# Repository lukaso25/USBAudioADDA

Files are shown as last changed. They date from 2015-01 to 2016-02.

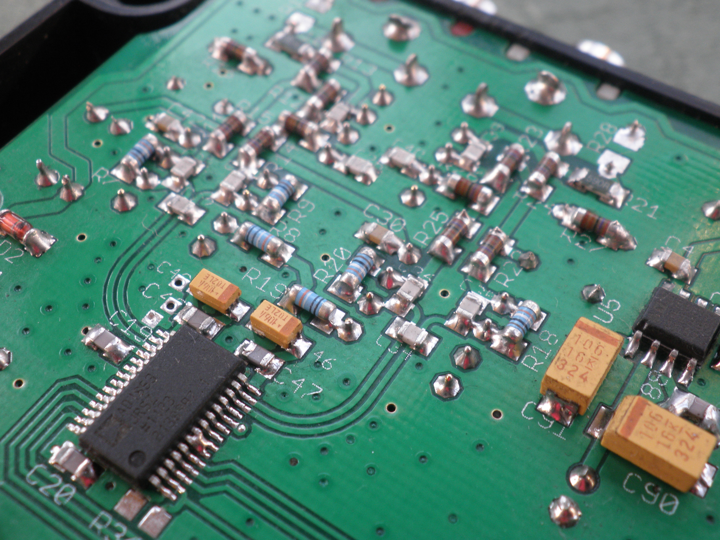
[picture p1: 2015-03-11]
photo prototype/04 dac section.JPG

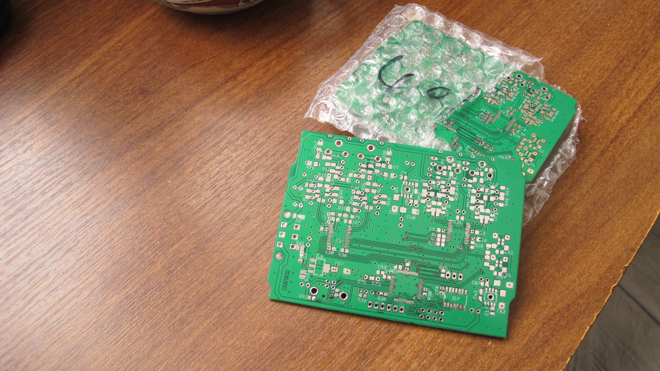
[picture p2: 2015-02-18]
photo prototype/01 pcb.JPG

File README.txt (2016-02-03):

USB Audio ADDA Async
--------------------

This repository contains resources of USB audio interface based on TI microcontroller and Analog devices AD and DA converters. This interface use UAC 1 USB audio specifications, asynchronous clocking scheme. Interface is 24 b/ 96(88.2) kHz  capable in half-duplex mode and 24b / 44.1(48) kHz in full-duplex. 

Only 2 SW modules are relased yet because of unfriendly licencing of USB example code.

Link to pcb photo https://raw.githubusercontent.com/lukaso25/USBAudioADDA/master/photo%20prototype/03%20bottom.JPG

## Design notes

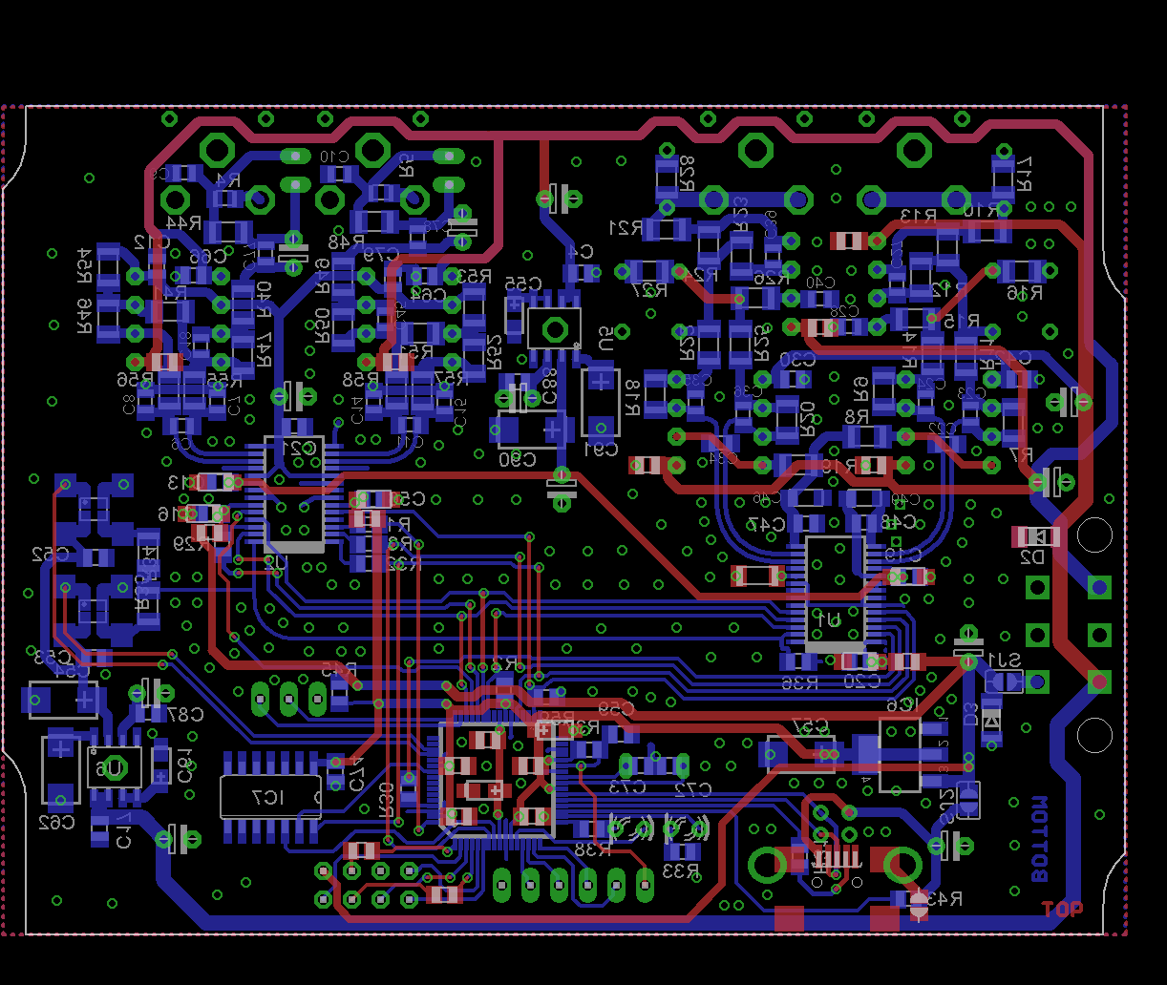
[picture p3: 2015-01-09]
pcbdesign/adcdac.png

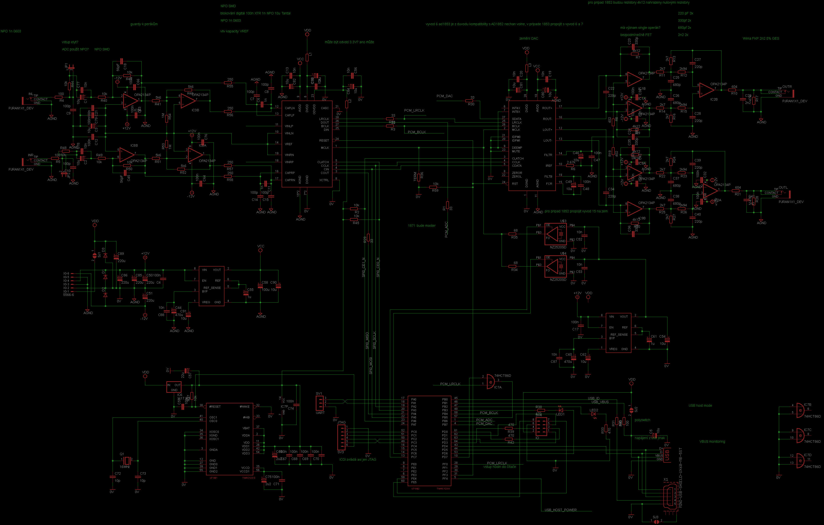
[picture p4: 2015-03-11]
pcbdesign/schema.png

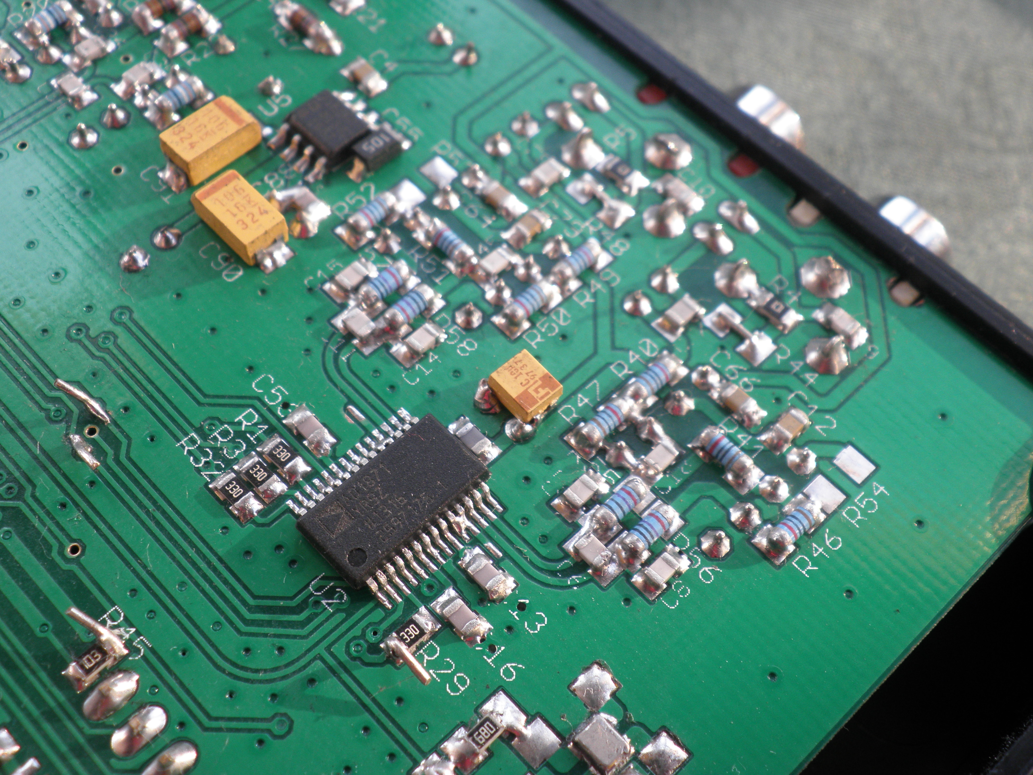
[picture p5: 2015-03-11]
photo prototype/05 ADC section.JPG

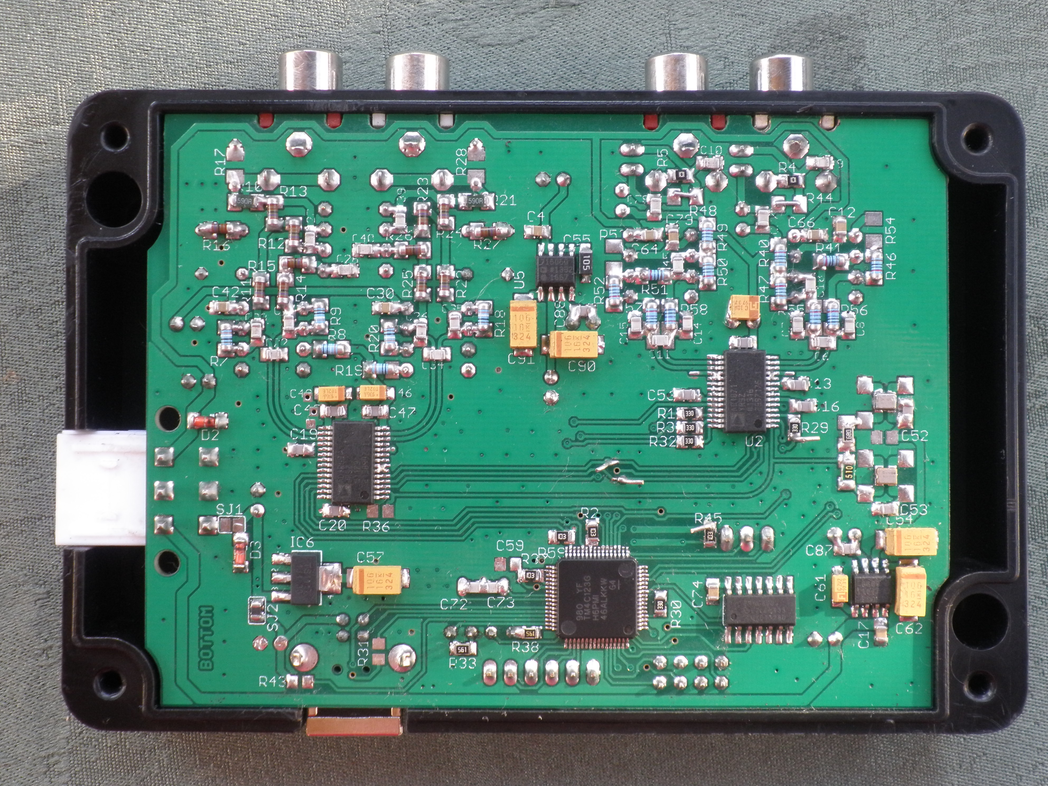
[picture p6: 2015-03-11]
photo prototype/03 bottom.JPG

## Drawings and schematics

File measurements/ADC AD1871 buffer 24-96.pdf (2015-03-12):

## RMS level

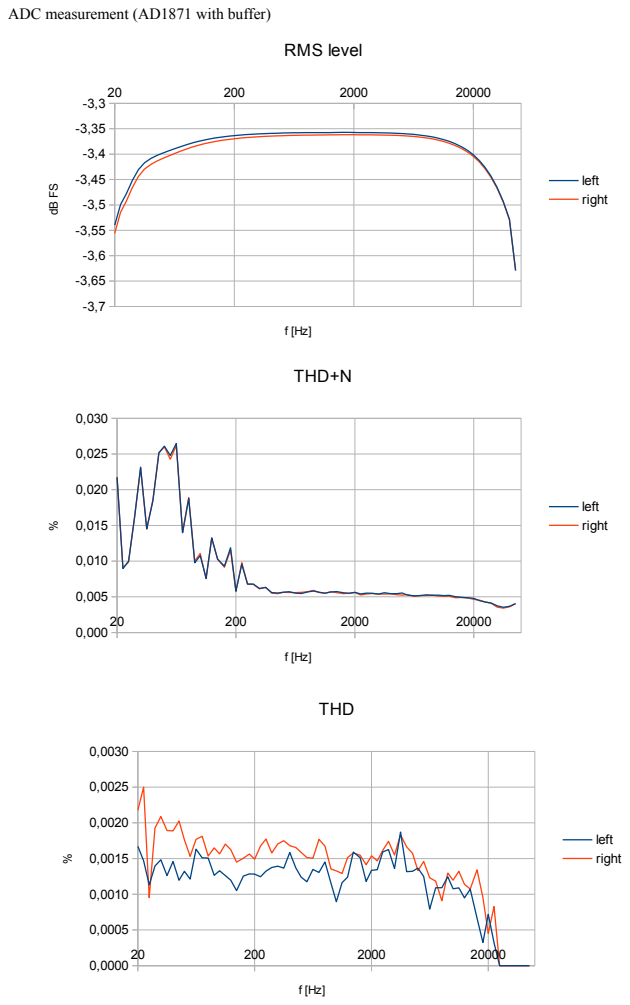
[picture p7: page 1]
left right; THD+N; THD

ADC measurement (AD1871 with buffer)

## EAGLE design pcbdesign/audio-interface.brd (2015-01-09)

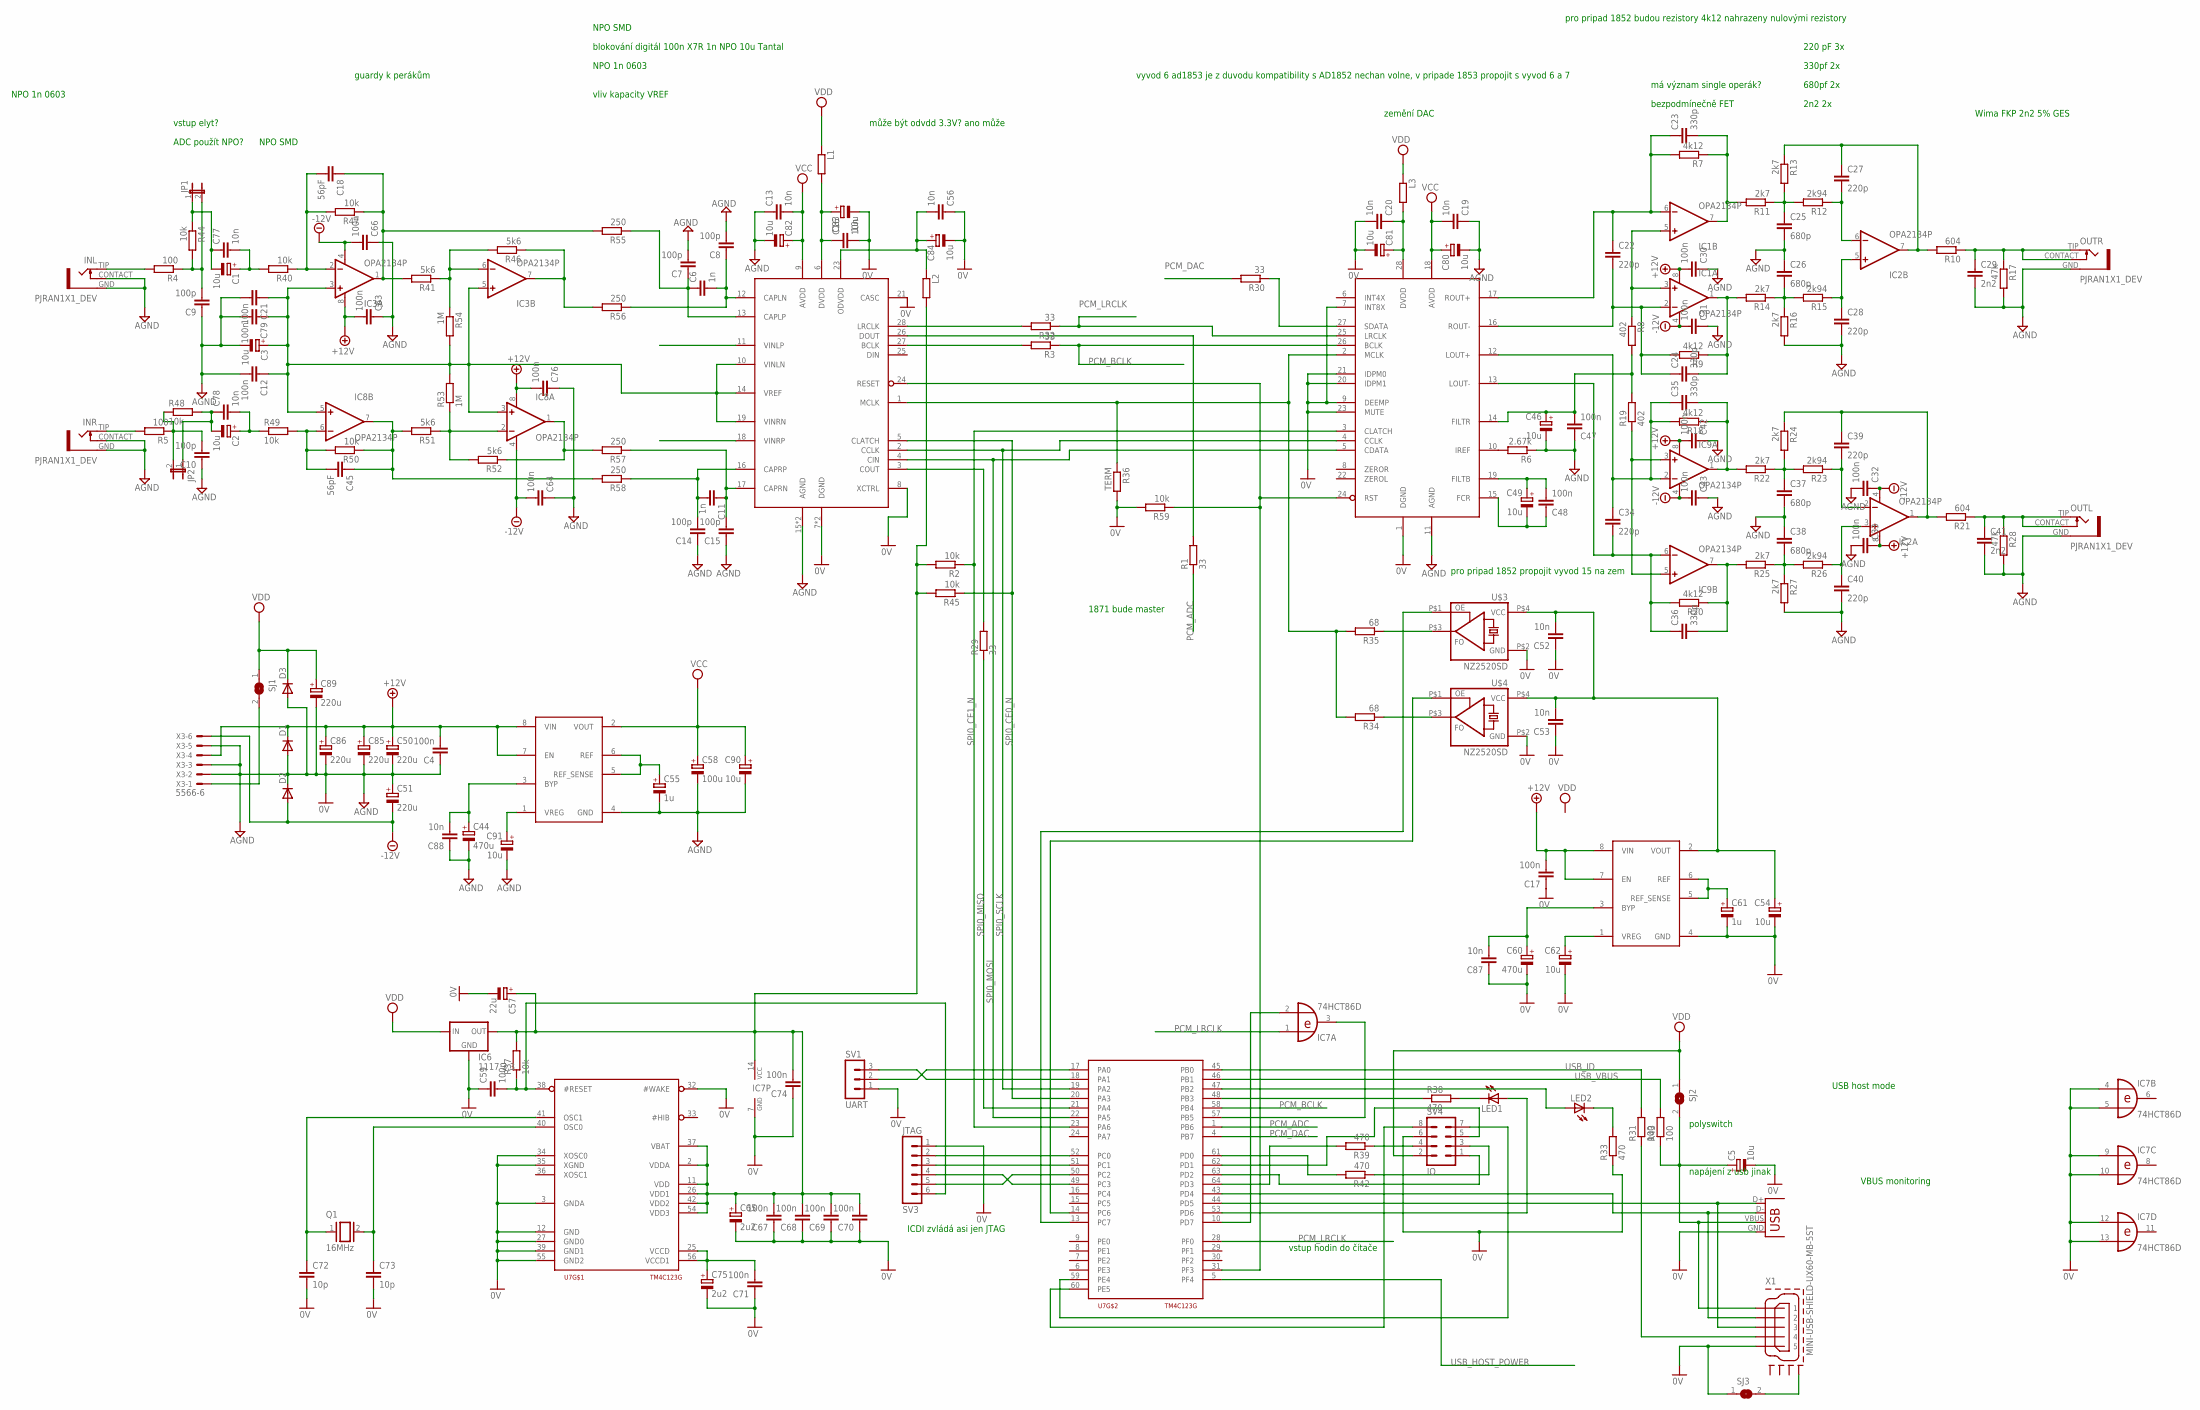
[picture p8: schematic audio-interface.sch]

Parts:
C1, C2: 10u; E2,5-5
C3, C5: 10u; E2,5-7
C4, C12, C17, C21, C30, C31, C32, C33, C42, C43, C47, C48, C59, C63, C64, C66, C67, C68, C69, C70, C71, C74, C76, C79: 100n; C0805
C6, C11: 1n; C0805K
C7, C8, C9, C10, C14, C15: 100p; C0805K
C13, C16, C19, C20, C52, C53, C56, C87, C88: 10n; C0805
C18, C45: 56pF; C0805K
C22, C27, C28, C34, C39, C40: 220p; C0805K
C23, C24, C35, C36: 330p; C0805K
C25, C26, C37, C38: 680p; C050-050X075
C29, C41: 2n2; C050-050X075
C44, C60: 470u; E2,5-7
C46, C49, C80, C81, C82, C83, C84: 10u; SMC_A
C50, C51, C85, C86, C89: 220u; E2,5-7
C54, C62, C90, C91: 10u; CT6032
C55, C61: 1u; CT3216
C57: 22u; CT6032
C58: 100u; E2,5-7
C65, C75: 2u2; CT3216
C72, C73: 10p; C0805
C77, C78: 10n; C0805K
D1, D2, D3: DIODE-MINIMELF; MINIMELF
IC1, IC3, IC8, IC9: OPA2134P; DIL08; MPN OPA2134PA
IC2: OPA2134P; DIL08
IC6: 1117 3.3; SOT223
IC7: 74HCT86D; SO14
INL: PJRAN1X1_DEV; PJRAN1X1
INR: PJRAN1X1_DEV; PJRAN1X1
JP1, JP2: JP1E; JP1
L1, L2, L3: R-EU_R0805; R0805
LED1, LED2: LED3MM
OUTL: PJRAN1X1_DEV; PJRAN1X1
OUTR: PJRAN1X1_DEV; PJRAN1X1
Q1: 16MHz; QS
R1, R3, R29, R30, R32: 33; R0805
R2, R37, R45, R59: 10k; R0805
R4, R5: 100; M0805
R6: 2.67k; M1406
R7, R9, R18, R20: 4k12; M1206
R8, R19: 402; M1206
R10, R21: 604; M1206
R11, R13, R14, R16, R22, R24, R25, R27: 2k7; M1206
R12, R15, R23, R26: 2k94; M1206
R17, R28: 47k; M1206
R31, R43: 100; R0805
R33, R38, R39, R42: 470; R0805
R34, R35: 68; M1206
R36: TERM; R0805
R40, R44, R47, R48, R49, R50: 10k; M1206
R41, R46, R51, R52: 5k6; M1206
R53, R54: 1M; M1206
R55, R56, R57, R58: 250; M1206
SJ1, SJ2, SJ3: SJ
SV1: UART; MA03-1
SV3: JTAG; MA06-1
SV4: IO; MA04-2
U1: AD1853; SSOP-28
U2: AD1871; SSOP-28
U5, U6: ADM7150; SO8-COOL
U7: TM4C123G; LQFP64
U$3, U$4: NZ2520SD; OSC2X2.5
X1: MINI-USB-SHIELD-UX60-MB-5ST; UX60-MB-5ST
X3: 5566-6
X7: USB-B-H

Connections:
+12V: C4.2, C17.2, C30.2, C33.1, C42.2, C50.+, C63.2, C76.2, C85.+, C86.+, D1.C, IC1.8 (V+), IC2.8 (V+), IC3.8 (V+), IC8.8 (V+), IC9.8 (V+), U5.7 (EN), U5.8 (VIN), U6.7 (EN), U6.8 (VIN), X3.4
-12V: C31.2, C32.1, C43.2, C51.-, C64.2, C66.2, D2.A, IC1.4 (V-), IC2.4 (V-), IC3.4 (V-), IC8.4 (V-), IC9.4 (V-), X3.6
AGND: C3.-, C4.1, C5.-, C7.2, C8.2, C9.1, C10.1, C12.2, C13.1, C14.1, C15.1, C16.2, C17.1, C19.1, C20.2, C21.2, C25.2, C26.1, C28.2, C29.2, C30.1, C31.1, C32.2, C33.2, C37.2, C38.1, C40.2, C41.2, C42.1, C43.1, C44.-, C46.-, C47.1, C50.-, C51.+, C52.1, C53.1, C54.-, C55.-, C56.1, C57.-, C58.-, C59.1, C60.-, C61.-, C62.-, C63.1, C64.1, C65.-, C66.1, C67.1, C68.1, C69.1, C70.1, C71.1, C72.2, C73.2, C74.1, C75.-, C76.1, C79.2, C80.-, C81.-, C82.-, C83.-, C84.-, C85.-, C86.-, C87.1, C88.1, C89.-, C90.-, C91.-, D1.A, D2.C, D3.A, IC6.1 (GND), IC7.4 (I0), IC7.5 (I1), IC7.7 (GND), IC7.9 (I0), IC7.10 (I1), IC7.12 (I0), IC7.13 (I1), INL.CONTACT (SWITCH), INL.GND, INR.CONTACT (SWITCH), INR.GND, OUTL.GND, OUTR.GND, R6.1, R16.2, R17.2, R27.2, R28.2, R33.1, R36.2, R59.2, SJ3.1, SV1.1, SV3.1, SV4.6, U1.1 (DGND), U1.7 (INT8X), U1.9 (DEEMP), U1.11 (AGND), U1.20 (IDPM1), U1.21 (IDPM0), U1.23 (MUTE), U2.7 (DGND), U2.8 (XCTRL), U2.15 (AGND), U2.20 (AGND), U2.21 (CASC), U2.22 (DGND), U5.4 (GND), U6.4 (GND), U7.3 (GNDA), U7.12 (GND), U7.27 (GND0), U7.32 (#WAKE), U7.34 (XOSC0), U7.35 (XGND), U7.39 (GND1), U7.55 (GND2), U$3.P$2 (GND), U$4.P$2 (GND), X1.5, X3.2, X3.3, X3.5, X7.GND
unnamed: R59.1, U1.24 (RST), U2.24 (RESET), U7.31 (PF3)
unnamed: R35.1, U$3.P$3 (FO)
unnamed: R32.2, U2.28 (LRCLK)
unnamed: IC7.3 (O), U7.57 (PB5)
unnamed: R1.2, U2.26 (DOUT)
unnamed: C55.+, U5.5 (REF_SENSE), U5.6 (REF)
unnamed: C91.+, U5.1 (VREG)
unnamed: C44.+, C88.2, U5.3 (BYP)
unnamed: R34.2, R35.2, R36.1, U1.2 (MCLK), U2.1 (MCLK)
unnamed: C6.2, C8.1, R56.1, U2.12 (CAPLN)
unnamed: R29.2, U2.3 (COUT)
unnamed: C60.+, C87.2, U6.3 (BYP)
unnamed: C62.+, U6.1 (VREG)
unnamed: C61.+, U6.5 (REF_SENSE), U6.6 (REF)
unnamed: C1.+, C77.2, R40.2
unnamed: IC3.7 (OUT), R46.1, R56.2
unnamed: C71.2, C75.+, U7.25 (VCCD), U7.56 (VCCD1)
unnamed: C22.2, C24.1, IC1.2 (-IN), R9.2, U1.16 (ROUT-)
unnamed: C6.1, C7.1, R55.1, U2.13 (CAPLP)
unnamed: C45.1, IC8.7 (OUT), R50.1, R51.2, R58.2
unnamed: C11.1, C15.2, R57.1, U2.17 (CAPRN)
unnamed: C22.1, C23.1, IC1.6 (-IN), R7.2, U1.17 (ROUT+)
unnamed: SV1.3, U7.18 (PA1)
unnamed: IC8.1 (OUT), R52.1, R57.2
unnamed: C24.2, IC1.1 (OUT), R9.1, R14.2
unnamed: C11.2, C14.2, R58.1, U2.16 (CAPRP)
unnamed: IC8.2 (-IN), R51.1, R52.2, R53.1
unnamed: IC3.6 (-IN), R41.1, R46.2, R54.1
unnamed: C3.+, C12.1, C21.1, C79.1, IC3.3 (+IN), IC3.5 (+IN), IC8.3 (+IN), IC8.5 (+IN), R53.2, R54.2, U2.10 (VINLN), U2.14 (VREF), U2.19 (VINRN)
unnamed: C23.2, IC1.7 (OUT), R7.1, R11.2
unnamed: C46.+, C47.2, R8.2, R19.2, U1.14 (FILTR)
unnamed: C26.2, R14.1, R15.2, R16.1
unnamed: R6.2, U1.10 (IREF)
unnamed: C25.1, R11.1, R12.2, R13.2
unnamed: C27.2, IC2.6 (-IN), R12.1
unnamed: C28.1, IC2.5 (+IN), R15.1
unnamed: C27.1, IC2.7 (OUT), R10.2, R13.1
unnamed: C48.2, C49.+, U1.19 (FILTB)
unnamed: C29.1, OUTR.CONTACT (SWITCH), OUTR.TIP (HOT), R10.1, R17.1
unnamed: C48.1, C49.-, U1.15 (FCR)
unnamed: SV3.5, U7.50 (PC2)
unnamed: C34.2, C36.1, IC9.6 (-IN), R20.2, U1.13 (LOUT-)
unnamed: C36.2, IC9.7 (OUT), R20.1, R25.2
unnamed: IC9.3 (+IN), IC9.5 (+IN), R19.1
unnamed: C35.2, IC9.1 (OUT), R18.1, R22.2
unnamed: C38.2, R25.1, R26.2, R27.1
unnamed: C37.1, R22.1, R23.2, R24.2
unnamed: C39.2, IC2.2 (-IN), R23.1
unnamed: C40.1, IC2.3 (+IN), R26.1
unnamed: C39.1, IC2.1 (OUT), R21.2, R24.1
unnamed: R3.2, U2.27 (BCLK)
unnamed: IC1.3 (+IN), IC1.5 (+IN), R8.1
unnamed: C18.1, IC3.1 (OUT), R41.2, R47.1, R55.2
unnamed: INR.TIP (HOT), R5.2
unnamed: C10.2, JP2.2, R5.1, R48.1
unnamed: R34.1, U$4.P$3 (FO)
unnamed: C34.1, C35.1, IC9.2 (-IN), R18.2, U1.12 (LOUT+)
unnamed: C2.+, C78.2, R49.1
unnamed: C72.1, Q1.1, U7.41 (OSC1)
unnamed: C52.2, C53.2, C54.+, U6.2 (VOUT), U$3.P$4 (VCC), U$4.P$4 (VCC)
unnamed: C45.2, IC8.6 (-IN), R49.2, R50.2
unnamed: C73.1, Q1.2, U7.40 (OSC0)
unnamed: SV4.1, U7.63 (PD2)
unnamed: SV1.2, U7.17 (PA0)
unnamed: R39.2, U7.64 (PD3)
unnamed: SV3.4, U7.49 (PC3)
unnamed: LED1.A, U7.53 (PD6)
unnamed: C18.2, IC3.2 (-IN), R40.1, R47.2
unnamed: C9.2, JP1.2, R4.1, R44.2
unnamed: INL.TIP (HOT), R4.2
unnamed: U7.44 (PD5), X1.3, X7.D+
unnamed: U7.43 (PD4), X1.2, X7.D-
unnamed: C59.2, R37.1, SV3.6, U7.38 (#RESET)
unnamed: SV3.2, U7.52 (PC0)
unnamed: SV3.3, U7.51 (PC1)
unnamed: IC7.2 (I1), U7.10 (PD7)
unnamed: LED2.K (C), R33.2
unnamed: LED1.K (C), R38.2
unnamed: U7.14 (PC6), U$4.P$1 (OE)
unnamed: U7.13 (PC7), U$3.P$1 (OE)
unnamed: R42.2, U7.61 (PD0)
unnamed: C16.1, C83.+, L1.2, U2.6 (DVDD)
unnamed: C56.2, C84.+, L2.1, U2.23 (ODVDD)
unnamed: R38.1, U7.48 (PB3)
unnamed: C57.+, C65.+, C67.2, C68.2, C69.2, C70.2, C74.2, IC6.2 (OUT), IC7.14 (VCC), L2.2, R2.2, R37.2, R45.2, U7.2 (VDDA), U7.11 (VDD), U7.26 (VDD1), U7.37 (VBAT), U7.42 (VDD2), U7.54 (VDD3)
unnamed: R30.1, U1.27 (SDATA)
unnamed: R39.1, SV4.4
unnamed: SV4.8, U7.60 (PE5)
unnamed: SV4.5, U7.62 (PD1)
unnamed: R42.1, SV4.3
unnamed: SV4.7, U7.59 (PE4)
unnamed: C1.-, C77.1, JP1.1, R44.1
unnamed: C2.-, C78.1, JP2.1, R48.2
unnamed: LED2.A, U7.47 (PB2)
unnamed: C20.1, C81.+, L3.2, U1.28 (DVDD)
unnamed: SJ1.2, X3.1
unnamed: C5.+, R43.1, SJ2.2, X1.1, X7.VBUS
unnamed: R31.1, X1.4
unnamed: SJ3.2, X1.M4 (GND4)
OUTL: C41.1, OUTL.CONTACT (SWITCH), OUTL.TIP (HOT), R21.1, R28.1
PCM_ADC: R1.1, U7.1 (PB6)
PCM_BCLK: R3.1, U1.26 (BCLK), U7.58 (PB4)
PCM_DAC: R30.2, U7.4 (PB7)
PCM_LRCLK: IC7.1 (I0), R32.1, U1.25 (LRCLK), U7.28 (PF0)
SPI0_CE0_N: R45.1, U2.5 (CLATCH), U7.20 (PA3)
SPI0_CE1_N: R2.1, U1.3 (CLATCH), U7.23 (PA6)
SPI0_MISO: R29.1, U7.21 (PA4)
SPI0_MOSI: U1.5 (CDATA), U2.4 (CIN), U7.22 (PA5)
SPI0_SCLK: U1.4 (CCLK), U2.2 (CCLK), U7.19 (PA2)
USB_HOST_POWER: U7.5 (PF4)
USB_ID: R31.2, U7.45 (PB0)
USB_VBUS: R43.2, U7.46 (PB1)
VCC: C13.2, C19.2, C58.+, C80.+, C82.+, C90.+, U1.18 (AVDD), U2.9 (AVDD), U5.2 (VOUT)
VDD: C89.+, D3.C, IC6.3 (IN), L1.1, L3.1, SJ1.1, SJ2.1, SV4.2

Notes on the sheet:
1871 bude master
bezpodmínečně FET
může být odvdd 3.3V? ano může
ICDI zvládá asi jen JTAG
USB host mode
vstup elyt?
ADC použít NPO?
NPO SMD
blokování digitál 100n X7R 1n NPO 10u Tantal
NPO 1n 0603
vliv kapacity VREF
zemění DAC
220 pF 3x
330pf 2x
680pf 2x
2n2 2x
má význam single operák?
Wima FKP 2n2 5% GES
vstup hodin do čítače
napájení z usb jinak
VBUS monitoring
guardy k perákům
polyswitch
vyvod 6 ad1853 je z duvodu kompatibility s AD1852 nechan volne, v pripade 1853 propojit s vyvod 6 a 7
pro pripad 1852 propojit vyvod 15 na zem
pro pripad 1852 budou rezistory 4k12 nahrazeny nulovými rezistory

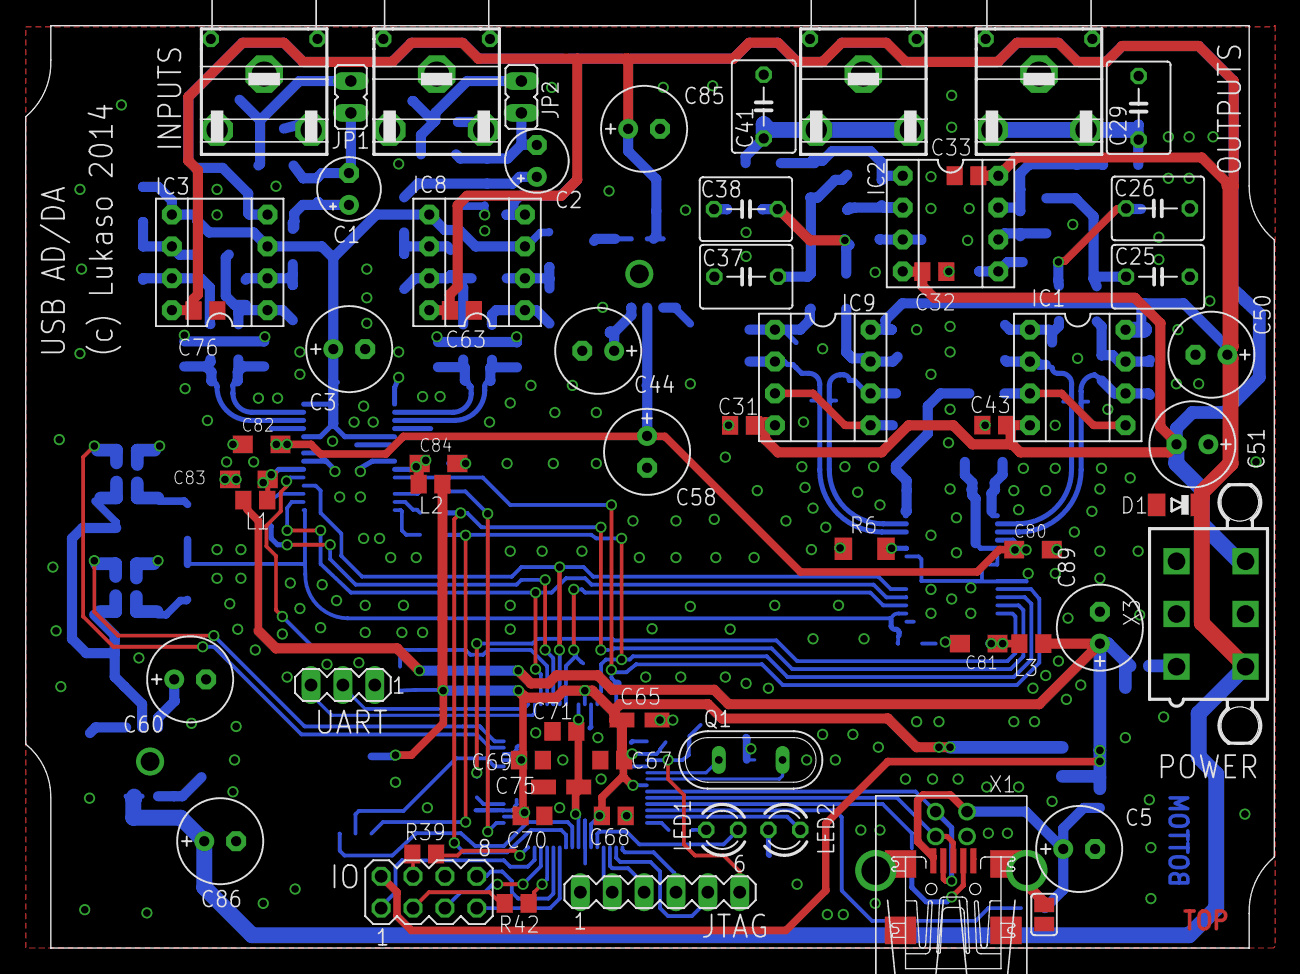
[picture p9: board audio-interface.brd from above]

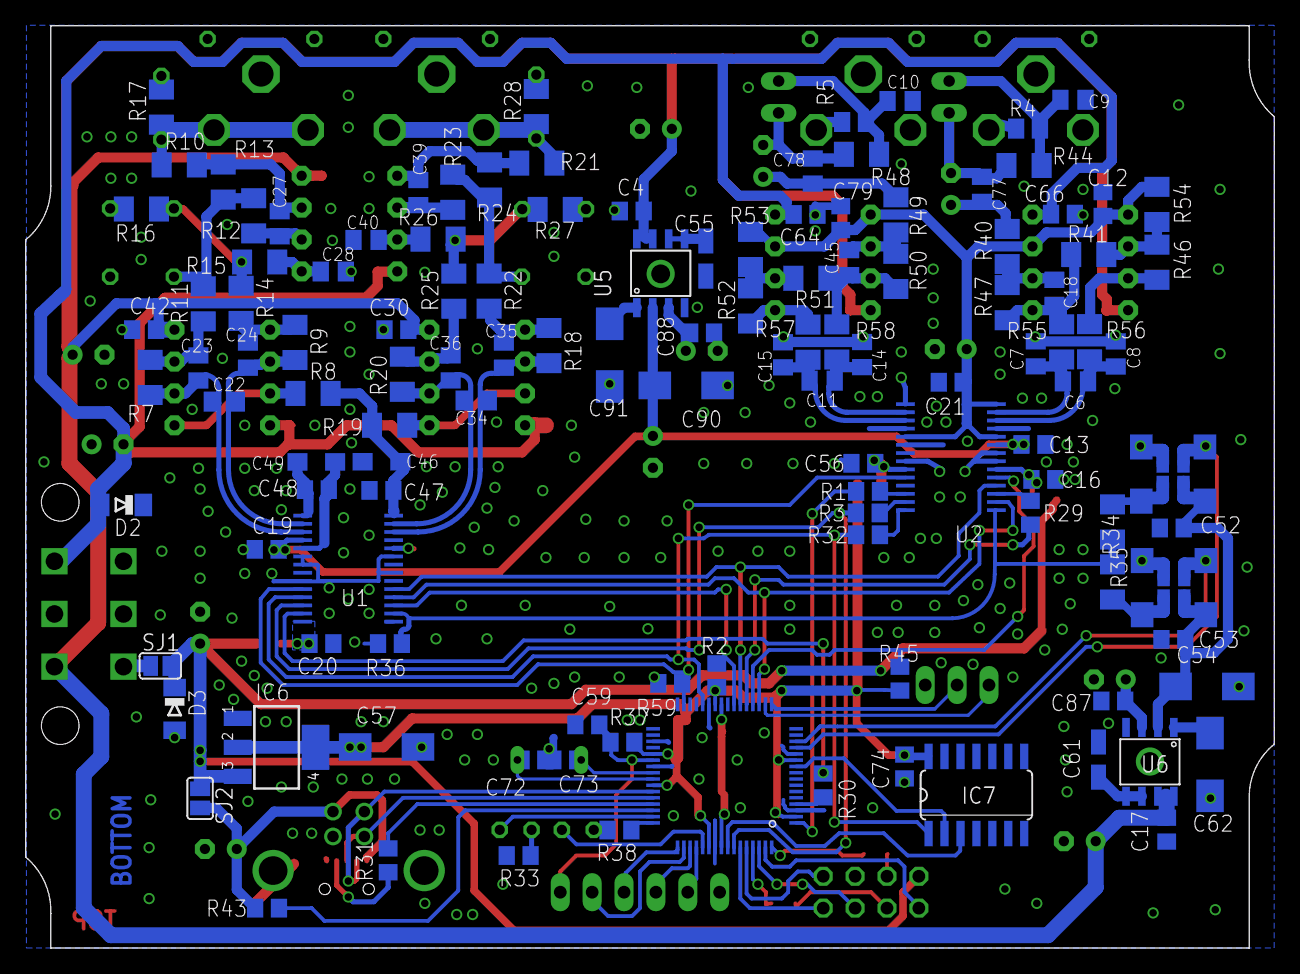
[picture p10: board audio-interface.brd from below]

Board: 2 copper layers, 99.5 x 73.5 mm, 188 parts (124 on the bottom side), 116 nets.

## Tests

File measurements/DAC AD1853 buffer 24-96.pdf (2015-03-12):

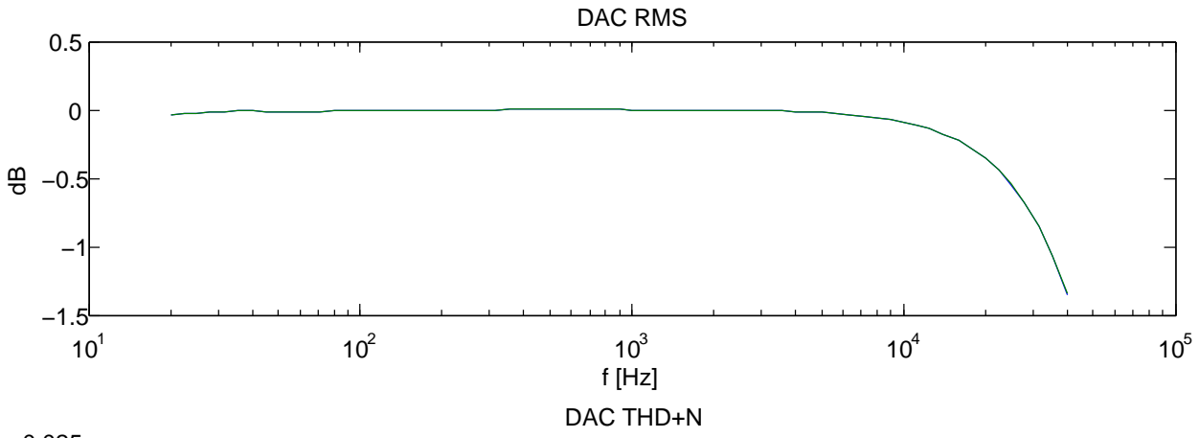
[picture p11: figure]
DAC RMS; DAC THD+N
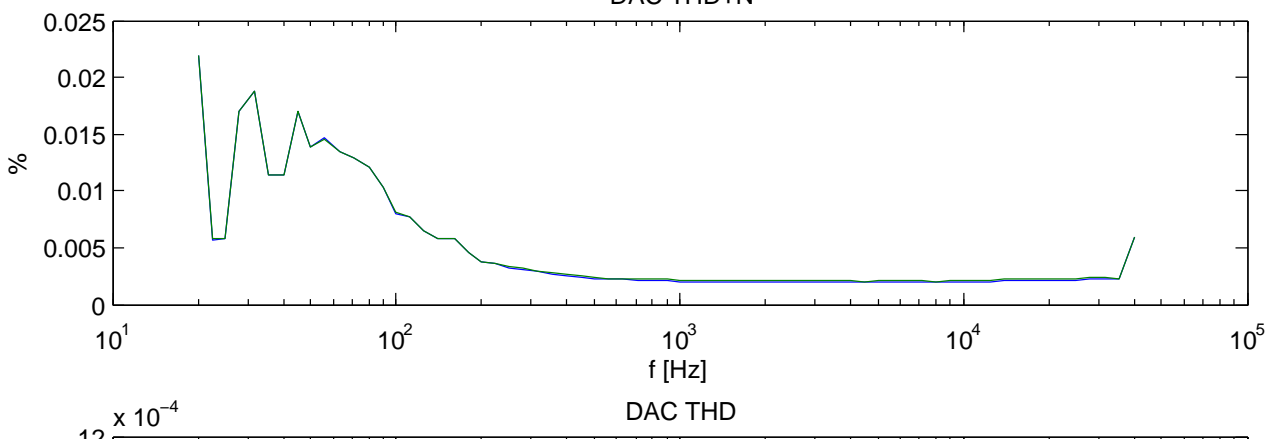
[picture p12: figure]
DAC THD
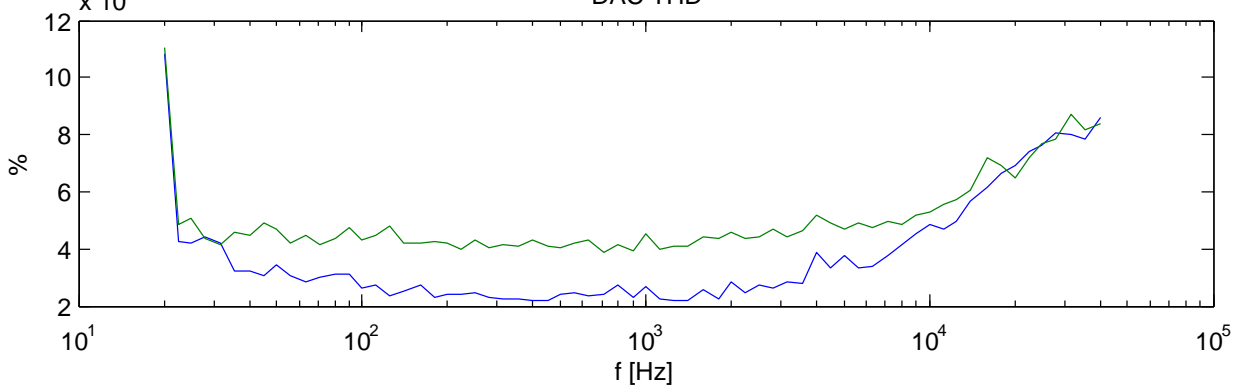
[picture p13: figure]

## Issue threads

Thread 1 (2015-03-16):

glitches during recording and monitoring

lukaso25, 2015-03-16:
There are some glitcher during recording with monitoring (full-duplex, observed in Samplitude 8 and Audacity DAW).

Testing suggestions:
- Is problem present on different UAC 1 device?
- Is problem related to synchronization of output (asynchronous audio).
- Is problem related only to MS Windows AUC1 audio implementation?

HW with current SW release should be debugged with loggic analyzer during recording initialization and recording glitches (output buffer state).

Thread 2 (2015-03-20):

Power management

lukaso25, 2015-03-20:
There are many problems with power management, which should be solved.

- what is specified by usb for suspend mode?
- what is actual power consumption during suspend mode?
- external power supply is used for analog, and sample rate clock  - how to handle absence of this supply, how to handle suspend signaling?

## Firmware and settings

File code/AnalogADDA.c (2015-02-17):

#include "AnalogADDA.h"

#include "inc/hw_memmap.h"
#include "inc/hw_types.h"
#include "inc/hw_ssi.h"
#include "inc/hw_gpio.h"
#include "inc/hw_ints.h"
#include "driverlib/ssi.h"
#include "driverlib/interrupt.h"
#include "driverlib/pin_map.h"
#include "driverlib/gpio.h"
#include "driverlib/rom.h"
#include "driverlib/sysctl.h"

#include "main.h"

uint32_t actual_samplerate;
static uint16_t AD1871_0_gain_hp_amc, AD1871_1_mute_fmt, AD1871_2_mux_mck;
static uint16_t AD185x_conf;
const uint16_t volumeLookUp[128];

uint16_t AnalogADDASPItransfer(uint8_t chip, uint16_t data);

uint16_t AnalogADDASPItransfer(uint8_t chip, uint16_t data)
{
	volatile uint16_t delay;
	GPIOPinWrite(GPIO_PORTA_BASE, chip, 0);
	//delay = 0xFF;
	//while (delay){delay--;};
	//temp = (1<<5)|1; // 24 bit, LJ, without mute
	SSIDataPut(SSI0_BASE,data);
	while(SSIBusy(SSI0_BASE)){};
	//delay = 0x0F;
	//while (delay){delay--;};
	GPIOPinWrite(GPIO_PORTA_BASE, chip, chip);
	delay = 0xFF;
	while (delay){delay--;};
	return 0;
}



uint16_t AnalogADDAInit( void)
{
	//temporary var
	//volatile uint32_t delay;
	//uint32_t temp,data,data1;
	uint32_t temp;

	//! konfigurace GPIO

	// LED GPIO
	SysCtlPeripheralEnable(SYSCTL_PERIPH_GPIOB);
	GPIOPinTypeGPIOOutput(GPIO_PORTB_BASE, GPIO_PIN_2);
	GPIOPinTypeGPIOOutput(GPIO_PORTB_BASE, GPIO_PIN_3);

	SysCtlPeripheralEnable(SYSCTL_PERIPH_GPIOD);
	GPIOPinTypeGPIOOutput(GPIO_PORTD_BASE, GPIO_PIN_6);


	// RESET GPIO
	SysCtlPeripheralEnable(SYSCTL_PERIPH_GPIOF);
	GPIOPinTypeGPIOOutput(GPIO_PORTF_BASE, GPIO_PIN_3);

	// Crystal GPIO
	SysCtlPeripheralEnable(SYSCTL_PERIPH_GPIOC);
	GPIOPinTypeGPIOOutput(GPIO_PORTC_BASE, GPIO_PIN_6);
	GPIOPinTypeGPIOOutput(GPIO_PORTC_BASE, GPIO_PIN_7);
	GPIOPinWrite(GPIO_PORTC_BASE, GPIO_PIN_7, 0);
	GPIOPinWrite(GPIO_PORTC_BASE, GPIO_PIN_6, 0);

	// SSI GPIO
	SysCtlPeripheralEnable(SYSCTL_PERIPH_GPIOA);
	GPIOPinTypeGPIOOutput(GPIO_PORTA_BASE, GPIO_PIN_3);
	GPIOPinTypeGPIOOutput(GPIO_PORTA_BASE, GPIO_PIN_6);

	// SSI alt function
	// The SSI peripheral must be enabled for use.
	SysCtlPeripheralEnable(SYSCTL_PERIPH_SSI0);
	GPIOPinConfigure(GPIO_PA2_SSI0CLK);
	GPIOPinConfigure(GPIO_PA4_SSI0RX);
	GPIOPinConfigure(GPIO_PA5_SSI0TX);
	GPIOPinTypeSSI(GPIO_PORTA_BASE, GPIO_PIN_2);
	GPIOPinTypeSSI(GPIO_PORTA_BASE, GPIO_PIN_4);
	GPIOPinTypeSSI(GPIO_PORTA_BASE, GPIO_PIN_5);

	// SSi sel
	GPIOPinWrite(GPIO_PORTA_BASE, GPIO_PIN_3, GPIO_PIN_3);
	GPIOPinWrite(GPIO_PORTA_BASE, GPIO_PIN_6, GPIO_PIN_6);


	// reset disable
	GPIOPinWrite(GPIO_PORTF_BASE, GPIO_PIN_3, GPIO_PIN_3);

	// crystal enable
	GPIOPinWrite(GPIO_PORTC_BASE, GPIO_PIN_7, GPIO_PIN_7);
	actual_samplerate = 48000;

#ifdef ADDA_ONLY_ONE_XTAL
	#warning "Only for One crystal oscilator configuration - special situation!"
	GPIOPinWrite(GPIO_PORTC_BASE, GPIO_PIN_6, GPIO_PIN_6);
	GPIOPinWrite(GPIO_PORTC_BASE, GPIO_PIN_7, GPIO_PIN_7);
#endif

	//! SSI configuration

	uint32_t clock = SysCtlClockGet();
	uint32_t SSIclk = 100000;

	// Clock configuration
	SSIConfigSetExpClk(SSI0_BASE, clock, SSI_FRF_MOTO_MODE_0, SSI_MODE_MASTER, SSIclk, 16);

	// Enable the each SSI module.
	SSIEnable(SSI0_BASE);

	// flushing receive FIFO
	while(SSIDataGetNonBlocking(SSI0_BASE, &temp)){};

	//! ADC configuration ----------------

	AD1871_2_mux_mck = 0x2000;
	// ADC MCLK divider & input configuration
#ifdef AD1871_ADCBUFFER_POPULATED
	// external ADC buffer
	AD1871_2_mux_mck |= (1<<3)|(1<<1);
#else
	// internal ADC single ended buffer
	AD1871_2_mux_mck |= (1<<5)|(1<<4);
#endif
	// default sample rate clock/2
	AD1871_2_mux_mck |= (1<<6);
	AnalogADDASPItransfer(GPIO_PIN_3, AD1871_2_mux_mck);

	AD1871_0_gain_hp_amc = 0;
	// High pass filter
#ifdef AD1871_HPF
	AD1871_0_gain_hp_amc |= (1<<8);
#endif
	AnalogADDASPItransfer(GPIO_PIN_3, AD1871_0_gain_hp_amc);

	AD1871_1_mute_fmt = 0x1000;
	// ADC desired format 24 bit LJ format 64fs
	AD1871_1_mute_fmt |= 0x60;
	AnalogADDASPItransfer(GPIO_PIN_3,AD1871_1_mute_fmt);

	//! DAC configuration ---------------

	AD185x_conf = 0x01;
	// DAC default format - format, filter desired format 24 bit LJ
	AD185x_conf |= (1<<5);
	AnalogADDASPItransfer(GPIO_PIN_6,AD185x_conf);


	uart_str("AD1871: ");
	uart_short_hex(AD1871_0_gain_hp_amc); uart_str(" ");
	uart_short_hex(AD1871_1_mute_fmt); uart_str(" ");
	uart_short_hex(AD1871_2_mux_mck);
	uart_str("\r\n");

	return 0;

}


uint32_t AnalogADDASetSampleRate( uint32_t rate )
{
	if (rate == actual_samplerate)
	{
		return rate;
	}
	else
	{
		actual_samplerate = rate;
	}

	//else
	switch (rate)
	{
	case 44100:
		// dìliè mck
		AD1871_2_mux_mck |=  (1<<6);
		AnalogADDASPItransfer(GPIO_PIN_3,AD1871_2_mux_mck);

		// amc vypneme
		AD1871_0_gain_hp_amc &= ~(1<<6);
		AnalogADDASPItransfer(GPIO_PIN_3,AD1871_0_gain_hp_amc);

		// odstraníme filtr 4x
		AD185x_conf &= ~(1<<10);
		AnalogADDASPItransfer(GPIO_PIN_6,AD185x_conf);

		GPIOPinWrite(GPIO_PORTC_BASE, GPIO_PIN_7, 0);
		GPIOPinWrite(GPIO_PORTC_BASE, GPIO_PIN_6, GPIO_PIN_6);
		break;
	case 88200:
		// dìliè mck
		AD1871_2_mux_mck &= ~(1<<6);
		AnalogADDASPItransfer(GPIO_PIN_3,AD1871_2_mux_mck);

		// amc zapneme
		AD1871_0_gain_hp_amc |= (1<<6);
		AnalogADDASPItransfer(GPIO_PIN_3,AD1871_0_gain_hp_amc);

		// nahodíme filtr 4x
		AD185x_conf |= (1<<10);
		AnalogADDASPItransfer(GPIO_PIN_6,AD185x_conf);

		GPIOPinWrite(GPIO_PORTC_BASE, GPIO_PIN_7, 0);
		GPIOPinWrite(GPIO_PORTC_BASE, GPIO_PIN_6, GPIO_PIN_6);
		break;
	case 48000:
		// dìliè mck
		AD1871_2_mux_mck |=  (1<<6);
		AnalogADDASPItransfer(GPIO_PIN_3,AD1871_2_mux_mck);

		// amc vypneme
		AD1871_0_gain_hp_amc &= ~(1<<6);
		AnalogADDASPItransfer(GPIO_PIN_3,AD1871_0_gain_hp_amc);

		// odstraníme filtr 4x
		AD185x_conf &= ~(1<<10);
		AnalogADDASPItransfer(GPIO_PIN_6,AD185x_conf);

		GPIOPinWrite(GPIO_PORTC_BASE, GPIO_PIN_6, 0);
		GPIOPinWrite(GPIO_PORTC_BASE, GPIO_PIN_7, GPIO_PIN_7);
		break;
	case 96000:
		// dìliè mck
		AD1871_2_mux_mck &= ~(1<<6);
		AnalogADDASPItransfer(GPIO_PIN_3,AD1871_2_mux_mck);

		// amc zapneme
		AD1871_0_gain_hp_amc |= (1<<6);
		AnalogADDASPItransfer(GPIO_PIN_3,AD1871_0_gain_hp_amc);

		// nahodíme filtr 4x
		AD185x_conf |= (1<<10);
		AnalogADDASPItransfer(GPIO_PIN_6,AD185x_conf);

		GPIOPinWrite(GPIO_PORTC_BASE, GPIO_PIN_6, 0);
		GPIOPinWrite(GPIO_PORTC_BASE, GPIO_PIN_7, GPIO_PIN_7);
		break;
	default:
		actual_samplerate = 0;
		break;
	}

	uart_str("AD1871: ");
	uart_short_hex(AD1871_0_gain_hp_amc); uart_str(" ");
	uart_short_hex(AD1871_1_mute_fmt); uart_str(" ");
	uart_short_hex(AD1871_2_mux_mck);
	uart_str("\r\n");

	// HW workaround
#ifdef ADDA_ONLY_ONE_XTAL
	#warning "Only for One crystal oscilator configuration - special situation!"
	GPIOPinWrite(GPIO_PORTC_BASE, GPIO_PIN_6, GPIO_PIN_6);
	GPIOPinWrite(GPIO_PORTC_BASE, GPIO_PIN_7, GPIO_PIN_7);
#endif

	return actual_samplerate;
}
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

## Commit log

2015-01-09 initial commit with HW files
    [audio-interface.brd, audio-interface.sch]
2015-01-25 ADC DAC code update, volume look-up tables
    Added code related to ADC and DAC; Added documentation - volume look-up
    table
    [volume_loopups.ods]
2015-03-11 bitmap schematics
2015-03-11 Readme updated, prototype photoes uploaded
2016-02-03 loopup modified
    [volume_loopups.ods]
